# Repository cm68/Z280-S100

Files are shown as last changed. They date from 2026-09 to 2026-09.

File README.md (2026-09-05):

# Z280 S-100 CPU Card

A 16-bit **Zilog Z280** CPU card for the **IEEE-696 S-100** backplane. All the
glue logic lives in two **Atmel ATF1508AS** CPLDs, and the entire schematic +
PCB are Python-generated (`gen_kicad.py`, `gen_pcb.py`).

## Key characteristics

| | |
|---|---|
| CPU | Zilog Z280, 16-bit, Z-BUS @ **12 MHz** |
| Bus | IEEE-696 S-100, 100-pin edge connector |
| Glue logic | 2× Atmel ATF1508AS (128 macrocells each) |
| RAM | **2 MB** SRAM — 4× IS61C5128AS-25 (512K×8, 25 ns), word-addressed as 1M×16 |
| Boot ROM | **64 KB** EEPROM — 2× AT28C256 (32K×8) |
| Console | RS-232 via MAX232, 2×5 IDC header (J7) |
| Data-bus drive | 74F245 — meets the IEEE-696 24 mA sink spec |

The board is a **bus master** by default: it drives address, status, control and
data onto the backplane. The CPLDs split the work cleanly:

- **Control CPLD** (`U4`, `z280-s100-ctl.pld`) — "the decider". Arbitration, the
  master-bridge state machine, local-memory control, and the pre-qualified
  steering terms (`MST_RD/MST_WR/SLV_RD/SLV_WR`, `XFR16`, `SPLIT`, `SLAVE`).
- **Data CPLD** (`U5`, `z280-s100-ad.pld`) — "everything that moves bits". The
  AD0-15 byte mux to the S-100 DO/DI lanes, the burst address counter, and the
  byte lane.

Address decode is external: a 74F138 (SRAM window) + two 74F521 comparators
(flash window, slave window). The A3–A15 address lines are latched out through
two 74F573s, and the 16-bit data bus runs through two 74F245 transceivers.

## Memory map (24-bit address space)

| Range | Size | Decode | Device |
|---|---|---|---|
| `000000`–`1FFFFF` | 2 MB | 74F138 (`SRAM_WIN`) / 74F521 (`SLAVE_WIN`) | SRAM — board + temporary-master access |
| `F00000`–`F0FFFF` | 64 KB | 74F521, A23:A16 = `F0` | Boot EEPROM |

The boot EEPROM pair is word-addressed (flash A_n = byte A_{n+1}), so the two
parts span 64 KB. They are *not* socket-interchangeable with 27C256s (pin 27 is
`WE#` here, not A14).

## Local-memory DMA (temporary-master access)

Another S-100 master can take the bus and read/write this card's local SRAM
directly — DMA-style, without the Z280:

1. The temporary master (TMA) asserts **HOLD**; the control CPLD forwards the
   request to the Z280 (`Z_BUSREQ`) and waits for `Z_BUSACK`.
2. With `Z_BUSACK` low the board is a **slave**
   (`SLAVE = !Z_BUSACK # SLAVE_ONLY`): the address/status/control 74F245s
   reverse direction, the data 74F245s float (`S100_DODSB`), and the 74F573
   address latches float their outputs.
3. The TMA reaches this card's RAM through the **slave window** — a
   74F521 comparator (`SLAVE_WIN`, hardwired to `000000`–`1FFFFF`) that maps
   the TMA's address space onto the local SRAM.

The **SLAVE_ONLY** strap (J11) forces this state permanently, turning the card
into a plain memory-only card for bring-up and debug.

## Burst mode

The Z280's memory burst mode (consecutive accesses without re-presenting the
address) is handled in the data CPLD:

- a **2-bit burst address counter** (A1/A2) increments during a burst;
- the **byte lane** (A0) is derived from the low-address bit and the 16→8
  **SPLIT** flag, so byte and word cycles share one data path;
- **16-bit transfers** are detected from WORD and the S-100 **SIXTN**
  (16-bit-acknowledge) line: `SPLIT16 = WORD & !SIXTN`.

`SIXTN` is open-collector (wired-OR) and pulled up via R4, like the ready lines.

## Clock options

Two 24 MHz time-base footprints are laid out; populate exactly **one**:

- **Y1** — parallel-resonant crystal (HC49) across `XTALI`/`XTALO`, or
- **Y2** — a DIP-can oscillator (DIP-8 or DIP-14) driving `XTALI`.

The Z280 auto-detects the source: a crystal enables the on-chip oscillator, while
an external clock into `XTALI` bypasses it (leave `XTALO` open). There is no
strap for this. Either way the CPU clock is half the XTAL1 frequency, so
**24 MHz → 12 MHz processor clock**.

## Configuration jumpers

### J10 — BTI register straps (3×8 header)

The Z280 samples AD0-7 on the rising edge of reset to load its **Bus Timing &
Initialization (BTI)** register — the wait-state field, clock divider,
bootstrap and multiprocessor bits. J10 is a 3×8 header, one row per bit: the
centre pin selects +5V (logic 1) or GND (logic 0); a 74HCT244 (U21) drives the
value onto AD0-7 for the whole reset window.

**Default = `0b10001110`** (AD7…AD0): direct clock, no bootstrap, no
multiprocessor, **3 wait states**, bus clock = CPU clock.

### J11 — SLAVE_ONLY

2-pin header. **Open (default)** = normal bus master. **Jumper to +5V** =
permanent slave (memory-only card). R3 (1 kΩ) holds the line low when open.

### SLAVE_WIN — temporary-master window

A 74F521 comparator hardwired to `000000`–`1FFFFF` (the same 2 MB window as
SRAM) selects where a temporary master sees this card's SRAM. Not user-
configurable on this rev.

### FLASH_WE — boot-ROM write protection

The 28C256 `WE#` line is normally driven by the control CPLD (in-system EEPROM
programming). Strap it to +5V to hard-write-protect the boot ROM.

## Repository layout

| Path | Purpose |
|---|---|
| `gen_kicad.py` | Generates the schematic (`.kicad_sch`, `.kicad_sym`, `NOTES.md`) |
| `gen_pcb.py` | Generates the board (`.kicad_pcb`) — components, nets, power planes |
| `sync_pcb.py` | Reads hand-tweaked PCB placement back into `gen_pcb.py` |
| `z280-s100-ctl.pld` | Control CPLD (U4) logic — arbitration, FSM, memory control |
| `z280-s100-ad.pld` | Data CPLD (U5) logic — byte mux, burst counter, byte lane |
| `z280-s100-*.jed` | Compiled CPLD fuse maps (fit with WinCUPL + ProChip, flashed over JTAG) |

CPLDs are flashed over the JTAG header (TDI/TMS/TCK/TDO on pins 14/23/62/71).

## License

[CERN Open Hardware Licence Version 2 - Permissive](LICENSE) (CERN-OHL-P-2.0).
Fork, modify and build it freely — just don't claim you designed it: keep the
attribution.

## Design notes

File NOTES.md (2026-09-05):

# Design notes

Signal connectivity follows `extra/docs/z280-s100-cpu-card.md`. This board is
routed and fabricated; the notes below are the as-built reference.

## Pin numbers
- **Z280 (U1)**: 68-pin PLCC pinout verified — Z80 Family Data Book Fig. 2b
  (Z-BUS, OPT=1), transcribed from `extra/docs/z280-pins.tif`. Power = 2× VCC
  (18/19) + 4× GND (1/35/51/53); shared pins GREQ=CTIO0 (30), GACK=CTIN0 (32),
  EOP-A=INT-A (37), EOP-B=INT-B (36).
- **ATF1508 (U4/U5)**: pin numbers are now verified against the PLCC-84 pinout
  and match `z280-s100-ctl.pld` / `z280-s100-ad.pld` — JTAG TDI/TMS/TCK/TDO
  at 14/23/62/71 (dedicated), VCCINT 3/43 + VCCIO 13/26/38/53/66/78, GND
  7/19/32/42/47/59/72/82. The four DEDICATED INPUT pins are GCLR = 1 (global
  clear, active low), OE2 = 2, GCLK1 = 83, OE1 = 84 — GCLR/OE1/OE2 are tied to
  +5V (inactive) on both CPLDs; GCLK1 = 83 carries Z_CLK_IN. Regular signals
  must NOT sit on pins 1/2/84. Control sits at 59/64 I/O; the data CPLD was at
  62/64 until the A3–A15 latch moved back out to two 74F573s (freeing pins for
  the DO_DIR/DI_DIR buffer controls), so it now sits near 50/64. The control
  CPLD still declares Z_AS (pin 12) as a spare input — unused since LATCH_LE
  moved to the data CPLD; the fitter drops it and pin 12 stays high-Z.
- **Unused CPLD I/O (free pins for a board rev 2):** data CPLD U5 has **65, 67,
  68, 69, 70, 73, 74** free (7). Control CPLD U4 has **75, 76, 77** free (3),
  plus **pin 12 (Z_AS)** as a spare — declared but unused, so high-Z in the
  JEDEC; its trace is routed on this rev but can be re-purposed on the next.
- **AT28C256 flash (U10/U11)**: 28-pin DIP, JEDEC 28C256 layout (A14=1, A12=2,
  A7=3 … A0=10, DQ0=11 … DQ7=19, CE#=20, A10=21, OE#=22, A11=23, A9=24, A8=25,
  A13=26, WE#=27, VCC=28, VSS=14). Word-addressed (flash A_n = byte A_{n+1}),
  so A0–A14 = LA1–LA15 and the pair spans 64 KB. Pin 27 is WE# here — where a
  27C256 has A14 — so the two are NOT socket-interchangeable. No density
  jumpers; a 28C128/28C64 fits if pin 1 (A14) is strapped low.

## Corrected S-100 pinout
Taken from `extra/hardware/s100z80/s100_Z80 V2-cache.lib` (S100_MALE). Key pins:
sMEMR=47, sWO=97, sINP=46, sOUT=45, sM1=44, sINTA=96, sHLTA=48, sXTRQ=58,
SIXTN=60, pSYNC=76, pDBIN=78, pWR=77, pSTVAL=25, pHLDA=26, pRDY=72, XRDY=3,
HOLD=74, RESET=75, INT=73, NMI=12, ADSB=22, DODSB=23, SDSB=18, CDSB=19,
DO0=36/DO1=35/DO2=88/DO3=89/DO4=38/DO5=39/DO6=40/DO7=90,
DI0=95/DI1=94/DI2=41/DI3=42/DI4=91/DI5=92/DI6=93/DI7=43.

## Serial console (J7, 2×5 IDC)
- J7 pin 1 = RS-232 TX (from MAX232 T1OUT), pin 2 = RS-232 RX (to MAX232 R1IN),
  pins 3–10 = GND.  Cable pin 1 → DB9-3, pin 2 → DB9-2, any GND → DB9-5.
- MAX232 (U14) charge-pump (C1/C2) + V+/V-/VCC bypass (C3/C4/C5), 0.1 µF each,
  are placed on the schematic (C1–C5) and the board.

## Bus timing straps (J10 3x8 header + U21)
- One 3x8 header (24 pins) sets the value the Z280 samples on AD0-7 at reset to
  load its Bus Timing & Initialization register (low-8M wait states + clock
  divider). One row per bit: col 0 = +5V (HIGH), col 1 = signal (BTI_ADn),
  col 2 = GND (LOW). Shunt col1→+5V = 1, col1→GND = 0.
- The 74HCT244 (U21) tri-state driver presents that value on AD0-7 during the
  reset-config window: both /OE (pins 1, 19) tie to CFG_OE from the control
  CPLD. The CPLD asserts WAIT >=4 clocks before reset rises and holds it 15
  clocks after (datasheet p.541/545; 6 is the floor, the extra is free since the
  CPU sits on WAIT), and CFG_OE tracks that same dwell, so AD0-7 stays driven
  through the rising-edge sample and its hold time.
- Default strap = 0b10001110 (AD7..AD0; AD0 = BTI bit 0): direct clock on
  XTAL1, no bootstrap, no multiprocessor, 3 wait states, bus clock = CPU clock.
  AD7/AD3/AD2/AD1 = high (+5V), AD6/AD5/AD4/AD0 = low (GND). Every bit stays
  jumperable, so the wait field and clock divider can be changed in place.
- Reset must be held low >=512 XTAL1 clocks (~21 us at 24 MHz); the DS1813's
  ~100 ms power-on reset easily satisfies this.

## Clock source (crystal Y1 vs DIP oscillator Y2)
- Two time-base options are laid out, both 24 MHz: a parallel-resonant crystal
  Y1 (HC49) across XTALI/XTALO, and a DIP-can oscillator Y2 whose OUT drives
  XTALI. Populate ONE at build time -- they must not both be fitted (they both
  drive XTALI).
- The Z280 auto-detects the source (datasheet 9.2): a crystal across XTAL1/XTALO
  enables the on-chip oscillator, while an external clock into XTAL1 bypasses it
  (leave XTALO open). There is NO strap bit for this -- the J10 BTI straps set
  the clock scaling (CS), wait states, multiprocessor and bootstrap fields, not
  the clock source. In both modes the CPU clock is half the XTAL1 frequency, so
  either 24 MHz part gives a 12 MHz processor clock.
- Y2's footprint (z280-s100:Oscillator_DIP-8-14) takes either a full DIP-14 can
  (GND/OUT on 7/8, VCC on 14) or a half DIP-8 can (GND/OUT on 4/5, VCC on 8).
  Pads 4/7 and 5/8 are shorted by the netlist, and pad 1 (NC) floats.

## Data bus (74F245 transceivers, U25/U26)
- The S-100 DO0-7 / DI0-7 lanes are NOT driven by the CPLD any more. CPLD B's
  byte mux drives CPLD_DO0-7 / CPLD_DI0-7 into the A-side of two 74F245s whose
  B-side is the backplane. 74F245 (64 mA sink / 15 mA source) meets the
  IEEE-696 data-bus drive spec that the ATF1508 macrocell outputs cannot.
- DIR = DO_DIR / DI_DIR from the data CPLD (1 = drive the bus). /OE is tied low:
  a 245 in receive mode never drives the bus, so only DIR has to be right, and
  the DIRs are gated by S100_DODSB so a temporary master can float our drivers.

## Address latch (74F573, U2/U3)
- A3-A15 moved out of CPLD B into two 74F573s to free pins for DO_DIR/DI_DIR.
  LE = LATCH_LE (= ~AS: transparent while AS is low, holds on the rising edge);
  /OE = SLAVE so the latch floats its Q outputs when a TMA drives address inward.
  A0 (byte lane) and A1/A2 (burst counter) stay in the CPLD — they need the
  SPLIT / load-count logic a plain latch can't do.
- U2 latches AD3-AD10 -> A3-A10, U3 latches AD11-AD15 -> A11-A15 (D5-D7 tied
  low, Q5-Q7 unused). The S-100 address 245s now take A0-A15 directly (the old
  LA1-LA15 net names were a stale leftover from the in-CPLD latch).
- Labelled 74F573 / 74F245 (64 mA sink, ~5 ns) to meet the IEEE-696 24 mA
  bus-drive spec and keep the address path ahead of the 25 ns SRAM. 74ACT573 /
  74ACT245 are drop-in pin-compatible substitutes at build time if the F parts
  draw too much +5V (ACT still sinks the 24 mA the spec needs, at CMOS quiescent).

## Known issues
See [BUGS.md](BUGS.md).

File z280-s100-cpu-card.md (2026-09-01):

# Z280 S-100 CPU Card

> Reference design · rev 0

A 16-bit **Z-BUS → IEEE-696** bridge: word-wide SRAM with burst instruction fetch, exposed as an S-100 slave so temporary-master disk controllers can DMA straight into main memory.

| | |
|---|---|
| **CPU** | Zilog Z280 · Z-BUS mode (`OPT = 1`) |
| **Glue** | 2 × Microchip ATF1508 CPLD (control + data path) |
| **Bus** | S-100 / IEEE-696 · 16-bit, 8-bit fallback |
| **Memory** | 2 MB word-wide SRAM (4 sockets) + flash boot |

---

## 1. What the card is

The Z280 talks a multiplexed 16-bit **Z-BUS**; the S-100 bus talks an Intel-style split **DO/DI** bus with a status-latch / ready handshake. The two don't line up, so the card is mostly two CPLDs plus a row of latches and bus drivers. Its job splits cleanly in two:

- **Fast path** — the on-card SRAM hangs directly off the Z-BUS. Address is demultiplexed by the `AS` strobe into a pair of `74HC573` latches; the control CPLD only does chip-select (plus the burst address counter). Zero wait states, so the Z280's on-chip 256-byte cache fills in **burst** at bus speed.
- **Slow path** — anything outside local memory becomes an S-100 cycle. The CPLD decodes the Z-BUS status lines into the S-100 status byte, drives `pSYNC`/`pDBIN`/`pWR`, and holds the Z280's `WAIT` line until the addressed slave asserts `pRDY`.

The third requirement — **temporary-master access to local SRAM** — turns the card into a bus slave too. When a disk controller asserts `HOLD`, the card parks the CPU and re-exposes its SRAM to the backplane at a jumper-selected address window, so a DMA controller can read and write it directly.

```mermaid
flowchart LR
  subgraph CPU["Z280 — Z-BUS mode"]
    Z["Z280<br/>AD0-15 · A16-23<br/>AS DS R/W B/W ST IE OE"]
  end
  subgraph GLUE["bus glue — two CPLDs"]
    L["74HC573 ×2<br/>address latch"]
    A["ATF1508 A<br/>control: FSM · status · arb · mem"]
    D["ATF1508 B<br/>data: byte steering · slave handshake"]
  end
  subgraph LOCAL["local memory — fast path"]
    R["SRAM 16-bit<br/>4 × 512K×8, 2 banks"]
    F["Flash 16-bit<br/>boot ROM"]
  end
  B["S-100 backplane<br/>A · DO/DI · status · timing"]

  Z -- AD0-15 --> L
  Z -- AD0-15 --> D
  L -- LA0-15 --> R
  L -- LA0-15 --> F
  L -- LA0-15 --> A
  Z -- "A16-23 AS DS R/W B/W ST IE OE BUSACK" --> A
  A -- "/CS /OE /WE + burst A0-1" --> R
  A -- "/CS /OE /WE" --> F
  A -- "SLAVE · MASTER_ACTIVE · MASTER_WRITE · BYTE_SEL · XFR16" --> D
  D -- "AD0-15" --> R
  D -- "AD0-15" --> F
  D -- "DO / DI" --> B
  D -- "SRAM_WIN · FLASH_WIN · A20" --> A
  A -- "address · status · pSYNC/pDBIN/pWR · pHLDA" --> B
  Z -- "WAIT · BUSREQ" --> A
  B -- "HOLD · pRDY · INT · SIXTN" --> A
  B -- "sMEMR/sWO/sXTRQ · ADSB/DODSB/SDSB/CDSB" --> D
```

*Block diagram — the control CPLD (A) routes each Z-BUS transaction to either the fast local path or the slow S-100 path; the data-path CPLD (B) steers bytes between the shared AD bus and the S-100 DO/DI lanes.*

---

## 2. The bridge: Z-BUS → S-100

### Status decode

The Z-BUS identifies a transaction with four status lines (`ST3–0`) plus `R/W`. The CPLD translates that into the S-100 status byte on the falling edge of `pSYNC`:

| Z-BUS ST3–0 | Meaning | S-100 status | Strobe |
|---|---|---|---|
| `1000` | CPU mem, cacheable | `sMEMR` (+ `sWO` if write) | pDBIN / pWR |
| `1001` | CPU mem, non-cacheable | `sMEMR` (+ `sWO` if write) | pDBIN / pWR |
| `0010` | I/O transaction | `sINP` (read) / `sOUT` (write) | pDBIN / pWR |
| `0011` | Halt | `sHLTA` | — |
| `0100–0111` | INT ack A/B/C, NMI | `sINTA` | pDBIN (vector read) |
| `0001` | Refresh | — | ignored |
| `1010, 11xx, 1110–1111` | EPU / test-and-set | — | not used here |

`sWO` is simply the complement of `R/W` (R/W low = write). The cacheable vs non-cacheable split comes *from* the Z280's MMU page attributes — the card doesn't decide it; it just routes both as memory. Non-cacheable pages are how the OS keeps DMA buffers coherent (see §4).

### Master cycle

The whole bridge is the `WAIT`-stretched cycle below. The Z280 raises `AS` to start; the control CPLD holds `WAIT` low for the entire off-card cycle and releases it only when `pRDY` (or `XRDY`) says the slave is done.

```mermaid
sequenceDiagram
  autonumber
  participant Z as Z280
  participant C as CPLD
  participant B as S-100 slave
  Z->>C: AS↑ (addr + ST + R/W valid)
  C->>Z: WAIT↓ — hold CPU
  C->>C: decode ST→s*, latch A0-15
  C->>B: A0-23 + status
  C->>B: pSYNC↑ then ↓ (slaves latch status)
  alt read (R/W high)
    C->>B: pDBIN↑
    B-->>C: pRDY↑ — data valid on DI
    C->>Z: WAIT↑ (release)
    Z->>Z: sample DI at DS edge
  else write (R/W low)
    C->>B: DO = data, pWR↓
    B-->>C: pRDY↑
    C->>Z: WAIT↑ (release)
  end
  C->>B: drop pDBIN/pWR, status, address
```

*Master-mode memory cycle — the Z280 is stretched with WAIT while the control CPLD runs the S-100 handshake underneath it.*

### 16-bit handshake

When the Z280 does a word access (`B/W` low), the control CPLD asserts `sXTRQ` during `pSYNC`. If the addressed slave answers `SIXTN`, the transfer goes through the full 16-bit path — the two data buses ganged per IEEE-696, `DO0–7` carrying the even byte (A0=0) and `DI0–7` the odd byte (A0=1). If not, the control CPLD splits it into two 8-bit cycles on the low lane — two `pSYNC` groups, byte-address bit steering the low byte first. That's the entire "8-bit fallback": a single register in the control CPLD that remembers the master asked for 16 bits and the slave said no.

> **Timing to verify:** the exact edge where the Z-BUS samples `WAIT` relative to `DS`, and the `AS` setup/hold for latching `AD0–15`, come from the Z-BUS timing figures in the manual (ch. 13) — follow those, not the Z80-bus description in ch. 12.

---

## 3. Local memory & burst fetch

Local SRAM is **word-wide**: four 8-bit parts in two banks, data lines tied straight to the shared `AD0–15` bus, address from the demux latch — except the low two word-address bits, which come from the burst counter in the control CPLD. Reads use the Z280's own `IE` as the SRAM `/OE`, writes use `DS` gated with `R/W` as `/WE` — so a local access is *not* an S-100 cycle at all, just decode + chip-select. That's what makes burst work.

The Z280's cache fill is not a separate bus protocol — there's no `BURST` pin. It is **one Address Strobe followed by four Data Strobes** (§13-9): the CPU presents the address once on `AS`, then issues four back-to-back reads on `DS` without re-asserting the address. The card must therefore auto-increment the word address between strokes — a 2-bit counter in the control CPLD steps the SRAM's low two word-address bits (`A1`/`A2`, byte `A0` stays 0) on each `DS`. Because the SRAM answers in a single bus cycle with no wait states, the fill runs at full bus rate. This only works because those fetches stay on the fast path; the moment a fetch crosses to the backplane it picks up S-100 wait states.

> **Part choice:** the `IS61C5128AS-25` (512K×8, 25 ns, 5 V) is far inside the 12 MHz bus cycle (≈83 ns) — zero wait states and full burst with no decode-timing constraint at all. Four of them give 2 MB word-wide in two banks (each chip is one byte lane, `A0` selects the lane; `A20` selects the bank). Keep the traces to these fast parts short and decouple them well.

### Address map (physical, bus-decode view)

| Range | Size | Target | Notes |
|---|---|---|---|
| `000000–1FFFFF` | 2 MB | Local SRAM | Micronix runtime; zero-wait, burst, cacheable; two banks via A20 |
| `F00000–F0FFFF` | 64 KB | Boot EEPROM | 2× 28C256 (28-pin); CPLD overlays flash on the reset vector at power-up, then remaps |
| `200000–EFFFFF` | ~14 MB | S-100 memory | Off-card memory cards; mark non-cacheable |
| `I/O 0000–FDFF` | 64 KB | S-100 I/O | Ports FE/FF stay on-chip (UART, timers, MMU) |

The local/S-100 split is a decode in the data-path CPLD (B) of the `A16–23` address window, so it's re-programmable. The reset-vector overlay is a small latch in the control CPLD: flash answers at the reset address until boot code writes a remap bit.

---

## 4. Slave mode: DMA into local SRAM

This is the requirement that makes the card a real S-100 citizen. A disk controller that wants to DMA into Micronix's buffers takes over the bus as a **temporary master**; the CPU card must then look like ordinary memory. The MPZ80, HD/DMA and DJ/DMA all implement the full IEEE-696 handoff, so this card must too. Arbitration and access:

```mermaid
sequenceDiagram
  autonumber
  participant T as Disk controller (TMA)
  participant C as CPLD
  participant Z as Z280
  participant S as Local SRAM
  T->>C: HOLD↓ + DMA priority on DMA0-3
  C->>Z: BUSREQ↓
  Z-->>C: BUSACK↓ — CPU floats its own AD/A/ST/AS/DS
  C-->>T: pHLDA↑ (BUSACK inverted)
  T->>C: ADSB↓ DODSB↓ SDSB↓ — float addr / data-out / status drivers
  T->>C: CDSB↓ — float control drivers
  T->>C: A0-23 + sMEMR/sWO
  alt address inside slave window
    C->>S: /CS + /OE (or byte-laned /WE)
    S-->>C: data (A0-selected byte lane)
    C-->>T: DI data + pRDY↑
  else outside window
    C-->>T: no response (some other card answers)
  end
  T->>C: deassert CDSB/DODSB/ADSB/SDSB, then HOLD↑
  C->>Z: BUSREQ↑
  Z-->>C: BUSACK↑ — CPU resumes
```

*Temporary-master arbitration — the CPU answers HOLD with pHLDA, the TMA floats the card's drivers with the four disable lines, then the card serves its SRAM as a slave.*

- **Driver handoff (required).** The TMA does not rely on the CPU floating itself — it takes the drivers over by asserting the four IEEE-696 disable lines: `ADSB*` (address), `DODSB*` (data-out), `SDSB*` (status), `CDSB*` (control). These gate the data-path CPLD's buffer output-enables. `pHLDA` is **not** gated by `CDSB*` — it is the permanent master's exclusive output and stays driven. There is exactly one bus master; each temporary master gets the bus by going *through* the master (a temporary never yields directly to another temporary), so `pHLDA` has no contention to float against. The HD/DMA floats data/address/status before control (two-step); the DJ/DMA asserts `CDSB*` first — either way all four must be honored.
- **Slave window.** The SRAM appears on the backplane at a jumper/CPLD-selected base — default `000000–0FFFFF` so a 20-bit (or even 16-bit) DMA controller can reach every byte. The window must not collide with other cards on the backplane.
- **Byte lane.** The Morrow DMA controllers are 8-bit, so a slave access is a single byte. The word-wide SRAM is built from four 8-bit parts in two banks; `A0` selects the lane and `A20` the bank: `/OE`/`/WE` go to the chip holding the addressed byte, and data moves on `DO0–7`/`DI0–7`. `SIXTN` is asserted only in answer to `sXTRQ`, so a 16-bit TMA still gets a 16-bit cycle.
- **Ready.** As a slave the card drives `pRDY`/`XRDY` after the SRAM access time, exactly like any memory card.

> **Cache coherency is the trap.** A TMA write lands in SRAM while the Z280's 256-byte cache may hold a stale copy of that line. Two fixes: mark the DMA/shared buffers **non-cacheable** in the MMU (ST = `1001`, so the CPU always hits the bus), or have the OS flush/invalidate the cache after each DMA — cheap, since the whole cache is only 256 bytes. Pick one and make it a hard rule in the DMA driver.

The Z280's own four-channel on-chip DMA (with `DMASTB`/`EOP`) remains available for on-card peripherals that want flyby transfers without bus arbitration — but it isn't needed for the temporary-master requirement above.

---

## 5. Signal interfaces

### Z-BUS side (ch. 13, signals this card uses)

| Signal | Dir | Active | Role on this card |
|---|---|---|---|
| `AD0–15` | bidir | high | muxed addr/data → latch (addr) + SRAM/flash data + DO/DI path |
| `A16–23` | out | high | upper address → decode + S-100 A16–23 |
| `AS` | out | low | address strobe — rising edge latches AD0-15, starts FSM |
| `DS` | out | low | data strobe — times data, reference for WAIT sample |
| `R/W` | out | low=wr | direction → sWO, SRAM /WE |
| `B/W` | out | low=word | word vs byte → sXTRQ / split |
| `ST3–0` | out | high | status → decoded to S-100 s* lines |
| `IE / OE` | out | low | read / write enables — gate DI into AD, AD onto DO/SRAM |
| `WAIT` | in | low | held low while an S-100 cycle completes |
| `BUSREQ / BUSACK` | in / out | low | bus handoff for temporary-master arbitration |
| `INT / NMI` | in | low | interrupts from backplane / local |
| `RESET` | in | low | power-on + S-100 pRESET |
| `XTALI/XTALO · CLK` | in/out | — | crystal in, bus clock out (FSM timing ref) |
| `OPT` | in | — | tie high = Z-BUS mode |
| `TxD / RxD` | out / in | high | console UART |

### S-100 side (signals this card drives or reads)

| Signal | Master | Slave | Purpose |
|---|---|---|---|
| `A0–23` | drive | receive | address |
| `DO0–7` | drive (write) | receive (write) | data out — the even byte (A0=0) |
| `DI0–7` | receive (read) | drive (read) | data in — the odd byte (A0=1) |
| `sMEMR/sWO/sINP/sOUT/sINTA/sHLTA` | drive | receive | status |
| `sXTRQ` | drive | receive | 16-bit request |
| `SIXTN` | receive | drive | 16-bit acknowledge |
| `pSYNC/pSTVAL/pDBIN/pWR` | drive | receive | cycle timing |
| `pHLDA` | drive | — | grant bus to a TMA (active high, from BUSACK) |
| `HOLD` | receive | — | temporary-master request |
| `ADSB` | receive | — | TMA disables my address drivers |
| `DODSB` | receive | — | TMA disables my data-out drivers |
| `SDSB` | receive | — | TMA disables my status drivers |
| `CDSB` | receive | — | TMA disables my control drivers |
| `pRDY / XRDY` | receive | drive | ready handshake |
| `INT / NMI / pRESET` | receive | receive | interrupts, reset |

> **Pin numbers** are per IEEE-696 and your backplane — the ones this card leans on are `pSYNC`=76, `pWR`=77, `pDBIN`=78, `sXTRQ`=58, `SIXTN`=60, `HOLD`=74, `pHLDA`=26 (active high), the disable lines `SDSB`=18, `CDSB`=19, `ADSB`=22, `DODSB`=23, power at 1 (+8V), 2 (+16V), 51 (+8V), 52 (−16V), 50/100 (GND). Confirm the address/data pins against the standard before wiring.

---

## 6. CPLDs: two ATF1508

Two **ATF1508** parts (128 macrocells, 5 V, JTAG/ISP, 84-pin PLCC, 64 I/O each) split the design down a clean seam: everything that *decides* a cycle lives in the **control CPLD (A)**, everything that *moves bytes* lives in the **data-path CPLD (B)**. The original single-part design used ~70 macrocells but 69 general I/O — past the 64-I/O ceiling — so two parts give 128 I/O and 256 macrocells of headroom. Bonus: each CPLD re-spins independently over JTAG, so a master-FSM fix doesn't touch the byte steering and vice versa.

### Control CPLD (A) — the decider

Owns the Z-BUS interface and never touches a data line:

- **Master FSM** — idles until `AS`, decides local vs S-100, runs the WAIT-stretched S-100 handshake, and holds the 16→8 split latch.
- **Status/control generation** — decodes `ST3–0` into the S-100 status byte and the `pSYNC`/`pDBIN`/`pWR` timing.
- **Local memory control** — SRAM/flash chip-selects, byte-laned `/WE`, and the **burst counter** (the 2-bit loadable counter that auto-increments the SRAM word address on each `DS`).
- **Arbitration** — `HOLD`→`BUSREQ`→`pHLDA` and the `SLAVE`/`MASTER` split.
- **Interrupts** — `INT`/`NMI` routing.

It only *reads* `pRDY`/`XRDY`/`SIXTN`; the open-drain drive of those lives in B.

### Data-path CPLD (B) — the mover

Hangs `AD0–15` (16 bidir) on the shared AD bus and does the IEEE-696 even/odd byte steering *inside*, driving `DO0–7`/`DI0–7` out through two **74F245** transceivers — the ATF1508 macrocell outputs can't meet the IEEE-696 24 mA data-bus sink spec on their own:

- **Byte mux (2×2 crossbar)** — `DO0–7` carries the even byte (A0=0), `DI0–7` the odd (A0=1); the mux steers each byte to the right `AD` lane and reverses for 8-bit split cycles.
- **Data-bus buffers** — `DO_DIR`/`DI_DIR` outputs drive the two 74F245 `DIR` pins (`/OE` tied low); both are `DODSB`-gated so a temporary master can float the data drivers.
- **Address latch** — the plain `A3–A15` half of the demux latch lives in two 74HC573s (`LATCH_LE = ~AS`, `/OE = SLAVE`), freeing pins for `DO_DIR`/`DI_DIR`; `A0` (byte lane) and `A1`/`A2` (burst counter) stay here.
- **Slave handshake** — open-drain `SIXTN`/`pRDY`/`XRDY` drive.
- **Buffer OE/DIR** — the address/status/control 74HCT245 drivers, gated by `ADSB`/`SDSB`/`CDSB`.

### Handoff between the two

Five steering decisions A computes that B can't see, three decode lines B computes that A needs:

```
A ──► B:  SLAVE · MASTER_ACTIVE · MASTER_WRITE · BYTE_SEL · XFR16
B ──► A:  SRAM_WIN · FLASH_WIN · A20
```

### Pin budgets

| CPLD | Inputs | Bidir | Outputs | Total signals |
|---|---|---|---|---|
| A — control | 25 | 8 | 28 | 61 |
| B — data path | 11 | 33 | 6 | 50 |

Both fit the 60 general I/O + GCK1 on the 84-pin PLCC (the four JTAG pins are dedicated). The 7 ns grade is fine — two parts cost nothing new when they're already on hand. Moving the `A3–A15` latch out to the 74HC573s dropped the data CPLD from ~100% I/O to 53/64 (82%).

### JTAG programming

One 1×6 header programs both parts in a single chain: `TCK`/`TMS` wired in parallel, `TDI`→A→B→`TDO` in series. The ISP tool selects a device positionally — chain order, not an address — by loading the target's ISP instruction and BYPASS into the others, then shifting data to just that part (see §9).

---

## 7. I/O, clock, power

**Console.** The Z280's on-chip UART is the console. `TxD`/`RxD` go through a `MAX232` (or 1488/1489) to a DE-9 — no SIO card needed. Baud from the on-chip generator if available, else a 1.8432 MHz oscillator for standard rates.

**Interrupts.** Backplane `INT` → Z280 `INT` (level), `NMI` → `NMI`. Vectored interrupts work via the `sINTA` cycle (ST = `0100–0111`), where the Z280 reads the vector off the bus like any I/O read — wire it if a controller needs it; otherwise keep interrupts flat.

**Clock.** A crystal on `XTALI`/`XTALO`; the processor clock is always **half the crystal frequency**, and the bus clock (output on `CLK`) is the processor clock divided by 1, 2, or 4 via the `CS` field of the Bus Timing & Initialization register (`00`=÷2 default, `01`=÷1, `10`=÷4, `11`=reserved). The `Z8028012` is rated for a **12 MHz processor clock**, so it needs a **24 MHz crystal** — the datasheet's "10 MHz"/"12.5 MHz" columns are processor clocks (XTALI = 20/25 MHz), confirming the part-number MHz is the CPU clock, not the crystal. For full-bore SRAM, set `CS`=`01` (÷1): the bus clock equals the CPU clock, **12 MHz**, so local SRAM runs zero-wait/burst at full speed while the CPLD WAIT-stretches off-card S-100 cycles to ≤6 MHz. `CS` is only writable at reset (WAIT asserted → `AD0–7` load); the ÷2 default gives a 6 MHz bus without that step. The BTI register value is set at reset by eight 3-pin jumpers (`J10–J17`) feeding a 74HCT244 (`U21`) whose tri-state outputs drive `AD0–7`; the control CPLD asserts WAIT ≥4 clocks before reset rises and holds it 15 clocks after (datasheet p.541/545; 6 is the floor, the rest is free), and `CFG_OE` tracks that same dwell to keep `AD0–7` driven through the sample. Default strap = `0b10001110` (AD7..AD0; AD4=0): direct clock, no bootstrap, no multiprocessor, 3 wait states, bus clock = CPU clock — the wait field and clock divider stay jumperable.

**Reset.** A reset supervisor (`DS1813`) holds `RESET` low ~100 ms at power-on, OR'd with backplane `pRESET`. The Z280 needs ≥512 XTAL1 clocks (~21 µs at 24 MHz) of reset, so the 100 ms is ample. The same net resets both CPLDs and re-asserts the flash-over-reset-vector latch.

**Power.** Regulate the +8 V rail down to +5 V with a `7805` (heatsink) or a small switcher. Budget ≈ 0.6 A: Z280 ~200 mA, two ATF1508s ~100 mA, four SRAMs, flash, drivers, MAX232. 4-layer board (power + ground planes), 0.1 µF per power pin plus bulk 10–47 µF.

---

## 8. Bill of materials

| Ref | Part | Notes |
|---|---|---|
| U1 | Zilog Z280MPU | 68-pin PLCC (or PGA); OPT tied high |
| U4 | Microchip ATF1508AS | 84-pin PLCC, 7 ns — control CPLD (A) |
| U5 | Microchip ATF1508AS | 84-pin PLCC, 7 ns — data-path CPLD (B) |
| U2–U3 | 74HC573 ×2 | address demux latch A3–A15 (`LATCH_LE = ~AS`, `/OE = SLAVE`; A0/A1/A2 stay in CPLD B) |
| U6–U9 | IS61C5128AS-25 ×4 | 512K×8, 25 ns SRAM = 2 MB word-wide, two banks (on DIP carriers) |
| U10–U11 | AT28C256 ×2 | 32K×8 EEPROM = 64 KB boot (28-pin DIP, JEDEC; no density jumpers) |
| U15–U17 | 74HCT245 ×3 | S-100 address drivers (A0–23) |
| U18 | 74HCT245 | S-100 status driver |
| U19 | 74HCT245 | S-100 control driver |
| U20 | 74HCT245 | pHLDA driver — one signal, full part (DIP-only constraint) |
| U25–U26 | 74F245 ×2 | S-100 data-bus transceivers (DO0-7, DI0-7) — 64 mA sink / 15 mA source meets IEEE-696 |
| U14 | MAX232 (or 1488/1489) | console level shifter |
| U13 | DS1813 | reset supervisor |
| U12 | PSU5a switcher | +5 V from +8 V rail, 3 A, no heatsink |
| Y1 | 24 MHz crystal | Z280 time base (CPU clock = crystal ÷ 2) |
| J2 | 1×6 pin header | JTAG programming chain (TDI→A→B→TDO) |
| J10–J17 | 3-pin jumper ×8 | BTI reset straps — set the AD0-7 reset value (wait states + clock divider) |
| U21 | 74HCT244 | tri-state BTI driver — presents the strap value on AD0-7 during reset, high-Z after |
| — | S-100 edge connector | 100-pin, gold fingers |

> Byte steering lives inside CPLD B, but the S-100 data lanes are now driven through two 74F245 transceivers (U25/U26) — the ATF1508 outputs can't meet the IEEE-696 data-bus drive spec. The address/status/control/pHLDA drivers (U15–U20) are 74HCT245; exact counts follow from the pin budget at PCB time.

---

## 9. Bring-up order

Build and test in this sequence — each step only exercises the previous one:

1. **Program the CPLDs** — chain both ATF1508s on the JTAG header and load `control.jed` (A, nearest TDI) and `data.jed` (B, nearest TDO). Verify each device enumerates in the chain.
2. **CPU alive** — Z280 + clock + reset only. Confirm `CLK`, that `RESET` is not stuck, and the CPU drives `AS`.
3. **Boot + RAM** — flash over the reset vector, SRAM decode. Run a monitor from flash; write/read/verify all 2 MB of SRAM (both banks) at full bus speed, then exercise a burst fill and check the word-address counter steps.
4. **Console** — get the on-chip UART speaking at the target baud before anything else.
5. **Master mode** — plug in a known-good S-100 memory card, read/write it through the bridge, confirm wait states hold the CPU correctly.
6. **16-bit** — exercise word accesses against a 16-bit-capable slave, then against an 8-bit-only card to prove the split.
7. **Slave mode** — from a second master (or a bus test jig), assert `HOLD`, DMA into the slave window, verify the CPU sees the bytes and the cache is coherent.

---

## 10. Open items to pin down

- **Reset vector location** — confirm where the Z280 fetches after reset (ch. 11) so the flash overlay sits at the right address.
- **Z-BUS timing figures** — exact `AS`/`DS`/`WAIT` edge relationships (ch. 13), for the WAIT-release register timing.
- **12 MHz bin spec** — resolved from `Z280-datasheet.pdf`: the 10/12.5 MHz columns are processor clocks (XTALI = 20/25 MHz), so `Z8028012` = 12 MHz CPU clock → 24 MHz crystal. Confirm the exact bin (12.0 vs 12.5 MHz) before ordering the crystal.
- **Cache control** — the exact way to mark a region non-cacheable, and/or the flush/invalidate sequence for the DMA driver.
- **Slave-window base** — agree the DMA address convention with whatever disk controller ships in this system.
- **Backplane pin map** — verify the IEEE-696 address/data pin numbers before netlisting.
- **ATF1508 pin map** — the `.pld` pin numbers are placeholders; verify against the 84-pin PLCC pinout (including the four dedicated JTAG pins) before netlisting.

---

## Sources

- [Konamiman/Z280TechnicalManual](https://github.com/Konamiman/Z280TechnicalManual) — transcript of the Zilog Z280 Technical Manual; Z-BUS pin functions and ST0–ST3 encodings (ch. 13), bus interface timing (ch. 12).
- [Zilog Z80 Family Data Book (1989)](https://archive.org/stream/Zilog-Z80familyDataBook1989OCR/Zilog-Z80familyDataBook1989OCR_djvu.txt) — Z280 pin configurations and Z-BUS functional blocks.
- [S-100 bus reference (retrocmp.de)](https://retrocmp.de/northstar-hrz/ns-hrz_p07_s100.htm) and the [S-100 Bus Handbook](https://archive.org/stream/Bus-TheS-100BusHandbook-DaveBurskyOCR/Bus-TheS-100BusHandbook-DaveBurskyOCR_djvu.txt) — IEEE-696 status, timing, and DMA signal definitions.

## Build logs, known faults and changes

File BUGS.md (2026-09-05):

# Known bugs

## S-100 bus RESET does not reset the board

The DS1813 (U13) power-on reset drives `Z_RESET` directly, but the S-100 bus
`RESET` line is not OR'd into it. As a result, an S-100 bus RESET (another bus
master, or a front-panel reset) will not reset the Z280 or the CPLDs — the card
only resets on power-on.

**Fix (board rev 2):** OR `S100_RESET` into `Z_RESET` before it reaches the
CPLD and the Z280 — a diode-OR of the DS1813 reset and `S100_RESET`, or route
`S100_RESET` into the control CPLD and OR it in logic.

## Future improvements

- **Configurable slave window** — `SLAVE_WIN` (U24 74F521) is hardwired to
  `000000`–`1FFFFF`, the same 2 MB window as `SRAM_WIN`. Strapping the
  high-order address lines (A16–A23) with jumpers or a DIP switch would let a
  temporary master see the local SRAM at a movable 2 MB window, avoiding
  address conflicts with other cards on the bus.

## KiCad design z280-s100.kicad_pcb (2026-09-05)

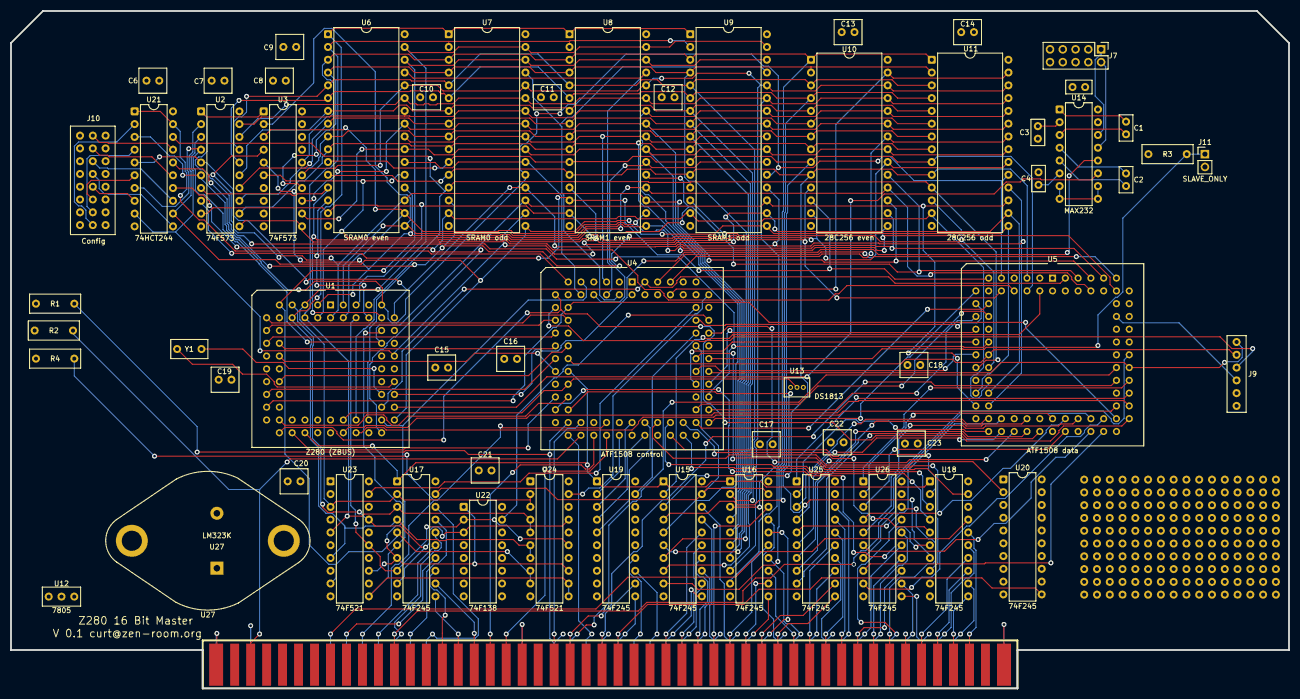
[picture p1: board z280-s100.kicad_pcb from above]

Board: 4 copper layers, 254.0 x 134.6 mm, 60 parts (0 on the bottom side), 202 nets.

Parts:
C1, C2, C3, C4, C5: 0.1uF; C_Disc_D5.0mm_W2.5mm_P2.50mm
C6, C7, C8, C9, C10, C11, C12, C13, C14, C15, C16, C17, C18, C19, C20, C21, C22, C23: 0.1uF; CAP-2
J7: Serial (2x5); PinHeader_2x05_P2.54mm_Vertical
J9: JTAG; HDR-6
J10: Config; HDR-3x8
J11: SLAVE_ONLY; PinHeader_1x02_P2.54mm_Vertical
R1: 1k pRDY; HDR-2
R2: 1k XRDY; HDR-2
R3: 1k SLAVE_ONLY; HDR-2
R4: 1k SIXTN; HDR-2
U1: Z280 (ZBUS); PLCC-68_THT-Socket
U2, U3: 74F573; DIP-20_W7.62mm
U4: ATF1508 control; PLCC-84_THT-Socket
U5: ATF1508 data; PLCC-84_THT-Socket
U6: SRAM0 even; DIP-32_W15.24mm
U7: SRAM0 odd; DIP-32_W15.24mm
U8: SRAM1 even; DIP-32_W15.24mm
U9: SRAM1 odd; DIP-32_W15.24mm
U10: 28C256 even; DIP-28_W15.24mm
U11: 28C256 odd; DIP-28_W15.24mm
U12: 7805; HDR-3
U13: DS1813; HDR-3
U14: MAX232; DIP-16_W7.62mm
U15, U16, U17, U18, U19, U20, U25, U26: 74F245; DIP-20_W7.62mm
U21: 74HCT244; DIP-20_W7.62mm
U22: 74F138; DIP-16_W7.62mm
U23, U24: 74F521; DIP-20_W7.62mm
U27: LM323K; TO-3
V 0.1 curt@zen-room.org: Z280 16 Bit Master; S100_MALE
Y1: 24 MHz crystal; HDR-2

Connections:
+5V: C5.1, C6.1, C7.1, C8.1, C9.1, C10.1, C11.1, C12.1, C13.1, C14.1, C15.1, C16.1, C17.1, C18.1, C19.1, C20.1, C21.1, C22.1, C23.1, J9.6, J10.1, J10.4, J10.7, J10.10, J10.13, J10.16, J10.19, J10.22, J11.2, R1.1, R2.1, R4.1, U1.18, U1.19, U1.34, U2.20, U3.20, U4.1, U4.2, U4.3, U4.13, U4.26, U4.38, U4.43, U4.53, U4.66, U4.78, U4.84, U5.1, U5.2, U5.3, U5.13, U5.26, U5.38, U5.43, U5.53, U5.66, U5.78, U5.84, U6.32, U7.32, U8.32, U9.32, U10.28, U11.28, U12.3, U13.3, U14.16, U15.20, U16.20, U17.20, U18.20, U19.20, U20.1, U20.20, U21.20, U22.6, U22.16, U23.12, U23.14, U23.16, U23.18, U23.20, U24.20, U25.20, U26.20, U27.2
+8V: U12.1, U27.1, V 0.1 curt@zen-room.org.1, V 0.1 curt@zen-room.org.51
A0: U5.4, U15.2
A1: U5.5, U6.12, U7.12, U8.12, U9.12, U10.10, U11.10, U15.3
A2: U5.6, U6.11, U7.11, U8.11, U9.11, U10.9, U11.9, U15.4
A3: U2.12, U6.10, U7.10, U8.10, U9.10, U10.8, U11.8, U15.5
A4: U2.13, U6.9, U7.9, U8.9, U9.9, U10.7, U11.7, U15.6
A5: U2.14, U6.8, U7.8, U8.8, U9.8, U10.6, U11.6, U15.7
A6: U2.15, U6.7, U7.7, U8.7, U9.7, U10.5, U11.5, U15.8
A7: U2.16, U6.6, U7.6, U8.6, U9.6, U10.4, U11.4, U15.9
A8: U2.17, U6.5, U7.5, U8.5, U9.5, U10.3, U11.3, U16.2
A9: U2.18, U6.27, U7.27, U8.27, U9.27, U10.25, U11.25, U16.3
A10: U2.19, U6.26, U7.26, U8.26, U9.26, U10.24, U11.24, U16.4
A11: U3.12, U6.23, U7.23, U8.23, U9.23, U10.21, U11.21, U16.5
A12: U3.13, U6.25, U7.25, U8.25, U9.25, U10.23, U11.23, U16.6
A13: U3.14, U6.4, U7.4, U8.4, U9.4, U10.2, U11.2, U16.7
A14: U3.15, U6.28, U7.28, U8.28, U9.28, U10.26, U11.26, U16.8
A15: U3.16, U6.3, U7.3, U8.3, U9.3, U10.1, U11.1, U16.9
A16: U1.5, U6.31, U7.31, U8.31, U9.31, U17.2, U23.3, U24.2, U24.3
A17: U1.6, U6.2, U7.2, U8.2, U9.2, U17.3, U23.5, U24.4, U24.5
A18: U1.8, U6.1, U7.1, U8.1, U9.1, U17.4, U23.7, U24.6, U24.7
A19: U1.9, U6.30, U7.30, U8.30, U9.30, U17.5, U23.9, U24.8, U24.9
A20: U1.45, U4.9, U17.6, U23.11, U24.11, U24.12
A21: U1.59, U17.7, U22.1, U23.13, U24.13
A22: U1.66, U17.8, U22.2, U23.15, U24.15
A23: U1.7, U17.9, U22.3, U23.17, U24.17
AD0: U1.40, U5.24, U7.13, U9.13, U11.11, U21.18
AD1: U1.42, U5.25, U7.14, U9.14, U11.12, U21.16
AD2: U1.43, U5.27, U7.15, U9.15, U11.13, U21.14
AD3: U1.44, U2.2, U5.28, U7.17, U9.17, U11.15, U21.12
AD4: U1.54, U2.3, U5.29, U7.18, U9.18, U11.16, U21.9
AD5: U1.57, U2.4, U5.30, U7.19, U9.19, U11.17, U21.7
AD6: U1.60, U2.5, U5.31, U7.20, U9.20, U11.18, U21.5
AD7: U1.61, U2.6, U5.9, U7.21, U9.21, U11.19, U21.3
AD8: U1.62, U2.7, U5.10, U6.13, U8.13, U10.11
AD9: U1.64, U2.8, U5.11, U6.14, U8.14, U10.12
AD10: U1.65, U2.9, U5.75, U6.15, U8.15, U10.13
AD11: U1.67, U3.2, U5.76, U6.17, U8.17, U10.15
AD12: U1.68, U3.3, U5.77, U6.18, U8.18, U10.16
AD13: U1.2, U3.4, U5.79, U6.19, U8.19, U10.17
AD14: U1.3, U3.5, U5.80, U6.20, U8.20, U10.18
AD15: U1.4, U3.6, U5.81, U6.21, U8.21, U10.19
BTI_AD0: J10.2, U21.2
BTI_AD1: J10.5, U21.4
BTI_AD2: J10.8, U21.6
BTI_AD3: J10.11, U21.8
BTI_AD4: J10.14, U21.11
BTI_AD5: J10.17, U21.13
BTI_AD6: J10.20, U21.15
BTI_AD7: J10.23, U21.17
CFG_OE: U4.11, U21.1, U21.19
CPLD_DI0: U5.44, U26.2
CPLD_DI1: U5.45, U26.3
CPLD_DI2: U5.46, U26.4
CPLD_DI3: U5.48, U26.5
CPLD_DI4: U5.49, U26.6
CPLD_DI5: U5.50, U26.7
CPLD_DI6: U5.51, U26.8
CPLD_DI7: U5.52, U26.9
CPLD_DO0: U5.33, U25.2
CPLD_DO1: U5.34, U25.3
CPLD_DO2: U5.35, U25.4
CPLD_DO3: U5.36, U25.5
CPLD_DO4: U5.37, U25.6
CPLD_DO5: U5.39, U25.7
CPLD_DO6: U5.40, U25.8
CPLD_DO7: U5.41, U25.9
CPLD_pDBIN: U4.45, U19.4
CPLD_pHLDA: U4.48, U20.2
CPLD_pSTVAL: U4.44, U19.3
CPLD_pSYNC: U4.41, U19.2
CPLD_pWR: U4.46, U19.5
CPLD_sHLTA: U4.31, U18.7
CPLD_sINP: U4.51, U18.4
CPLD_sINTA: U4.30, U18.6
CPLD_sMEMR: U4.49, U18.2
CPLD_sOUT: U4.52, U18.5
CPLD_sWO: U4.50, U18.3
CPLD_sXTRQ: U4.65, U18.8
DI_DIR: U5.60, U26.1
DO_DIR: U5.58, U25.1
FLASH_CE: U4.81, U10.20, U11.20
FLASH_OE: U4.79, U10.22, U11.22
FLASH_WE: U4.80, U10.27, U11.27
FLASH_WIN: U4.73, U23.19
GND: C3.2, C4.2, C5.2, C6.2, C7.2, C8.2, C9.2, C10.2, C11.2, C12.2, C13.2, C14.2, C15.2, C16.2, C17.2, C18.2, C19.2, C20.2, C21.2, C22.2, C23.2, J7.3, J7.4, J7.5, J7.6, J7.7, J7.8, J7.9, J7.10, J9.5, J10.3, J10.6, J10.9, J10.12, J10.15, J10.18, J10.21, J10.24, R3.1, U1.1, U1.35, U1.51, U1.53, U2.10, U3.7, U3.8, U3.9, U3.10, U4.7, U4.19, U4.32, U4.42, U4.47, U4.59, U4.72, U4.82, U5.7, U5.19, U5.32, U5.42, U5.47, U5.59, U5.72, U5.82, U6.16, U7.16, U8.16, U9.16, U10.14, U11.14, U12.2, U13.1, U14.15, U15.10, U16.10, U17.10, U18.10, U19.10, U20.3, U20.4, U20.5, U20.6, U20.7, U20.8, U20.9, U20.10, U20.19, U21.10, U22.4, U22.5, U22.8, U23.1, U23.2, U23.4, U23.6, U23.8, U23.10, U24.1, U24.10, U24.14, U24.16, U24.18, U25.10, U25.19, U26.10, U26.19, U27.3, V 0.1 curt@zen-room.org.20, V 0.1 curt@zen-room.org.50, V 0.1 curt@zen-room.org.53, V 0.1 curt@zen-room.org.70, V 0.1 curt@zen-room.org.100
JTAG_CHAIN: U4.71, U5.14
JTAG_TCK: J9.1, U4.62, U5.62
JTAG_TDI: J9.3, U4.14
JTAG_TDO: J9.4, U5.71
JTAG_TMS: J9.2, U4.23, U5.23
LA0: U4.63, U5.22
LATCH_LE: U2.11, U3.11, U5.8
MAX_C1M: C1.2, U14.3
MAX_C1P: C1.1, U14.1
MAX_C2M: C2.2, U14.5
MAX_C2P: C2.1, U14.4
MAX_RS232_RX: J7.2, U14.13
MAX_RS232_TX: J7.1, U14.14
MAX_VM: C4.1, U14.6
MAX_VP: C3.1, U14.2
MEM_CE0: U4.10, U6.22, U7.22
MEM_CE1: U4.8, U8.22, U9.22
MEM_OE: U4.5, U6.24, U7.24, U8.24, U9.24
MEM_WE_H: U4.4, U7.29, U9.29
MEM_WE_L: U4.6, U6.29, U8.29
MST_RD: U4.54, U5.12
MST_WR: U4.55, U5.15
NC: U14.7, U14.8, U14.9, U14.10
S100_A0: U15.11, V 0.1 curt@zen-room.org.79
S100_A1: U15.12, V 0.1 curt@zen-room.org.80
S100_A2: U15.13, V 0.1 curt@zen-room.org.81
S100_A3: U15.14, V 0.1 curt@zen-room.org.31
S100_A4: U15.15, V 0.1 curt@zen-room.org.30
S100_A5: U15.16, V 0.1 curt@zen-room.org.29
S100_A6: U15.17, V 0.1 curt@zen-room.org.82
S100_A7: U15.18, V 0.1 curt@zen-room.org.83
S100_A8: U16.11, V 0.1 curt@zen-room.org.84
S100_A9: U16.12, V 0.1 curt@zen-room.org.34
S100_A10: U16.13, V 0.1 curt@zen-room.org.37
S100_A11: U16.14, V 0.1 curt@zen-room.org.87
S100_A12: U16.15, V 0.1 curt@zen-room.org.33
S100_A13: U16.16, V 0.1 curt@zen-room.org.85
S100_A14: U16.17, V 0.1 curt@zen-room.org.86
S100_A15: U16.18, V 0.1 curt@zen-room.org.32
S100_A16: U17.11, V 0.1 curt@zen-room.org.16
S100_A17: U17.12, V 0.1 curt@zen-room.org.17
S100_A18: U17.13, V 0.1 curt@zen-room.org.15
S100_A19: U17.14, V 0.1 curt@zen-room.org.59
S100_A20: U17.15, V 0.1 curt@zen-room.org.61
S100_A21: U17.16, V 0.1 curt@zen-room.org.62
S100_A22: U17.17, V 0.1 curt@zen-room.org.63
S100_A23: U17.18, V 0.1 curt@zen-room.org.64
S100_ADSB: U4.36, V 0.1 curt@zen-room.org.22
S100_A_OE: U4.67, U15.19, U16.19, U17.19
S100_CDSB: U4.39, V 0.1 curt@zen-room.org.19
S100_C_OE: U4.69, U19.19
S100_DI0: U26.11, V 0.1 curt@zen-room.org.95
S100_DI1: U26.12, V 0.1 curt@zen-room.org.94
S100_DI2: U26.13, V 0.1 curt@zen-room.org.41
S100_DI3: U26.14, V 0.1 curt@zen-room.org.42
S100_DI4: U26.15, V 0.1 curt@zen-room.org.91
S100_DI5: U26.16, V 0.1 curt@zen-room.org.92
S100_DI6: U26.17, V 0.1 curt@zen-room.org.93
S100_DI7: U26.18, V 0.1 curt@zen-room.org.43
S100_DO0: U25.11, V 0.1 curt@zen-room.org.36
S100_DO1: U25.12, V 0.1 curt@zen-room.org.35
S100_DO2: U25.13, V 0.1 curt@zen-room.org.88
S100_DO3: U25.14, V 0.1 curt@zen-room.org.89
S100_DO4: U25.15, V 0.1 curt@zen-room.org.38
S100_DO5: U25.16, V 0.1 curt@zen-room.org.39
S100_DO6: U25.17, V 0.1 curt@zen-room.org.40
S100_DO7: U25.18, V 0.1 curt@zen-room.org.90
S100_DODSB: U5.61, V 0.1 curt@zen-room.org.23
S100_HOLD: U4.33, V 0.1 curt@zen-room.org.74
S100_INT: U5.63, V 0.1 curt@zen-room.org.73
S100_NMI: U5.64, V 0.1 curt@zen-room.org.12
S100_SDSB: U4.37, V 0.1 curt@zen-room.org.18
S100_SIXTN: R4.2, U4.40, V 0.1 curt@zen-room.org.60
S100_S_OE: U4.68, U18.19
S100_XRDY: R2.2, U4.35, V 0.1 curt@zen-room.org.3
S100_pDBIN: U19.13, V 0.1 curt@zen-room.org.78
S100_pHLDA: U20.11, V 0.1 curt@zen-room.org.26
S100_pRDY: R1.2, U4.34, V 0.1 curt@zen-room.org.72
S100_pSTVAL: U19.12, V 0.1 curt@zen-room.org.25
S100_pSYNC: U19.11, V 0.1 curt@zen-room.org.76
S100_pWR: U19.14, V 0.1 curt@zen-room.org.77
S100_sHLTA: U18.16, V 0.1 curt@zen-room.org.48
S100_sINP: U18.13, V 0.1 curt@zen-room.org.46
S100_sINTA: U18.15, V 0.1 curt@zen-room.org.96
S100_sMEMR: U18.11, V 0.1 curt@zen-room.org.47
S100_sOUT: U18.14, V 0.1 curt@zen-room.org.45
S100_sWO: U18.12, V 0.1 curt@zen-room.org.97
S100_sXTRQ: U18.17, V 0.1 curt@zen-room.org.58
SLAVE: U2.1, U3.1, U4.58, U5.21
SLAVE_ONLY: J11.1, R3.2, U4.64
SLAVE_WIN: U4.74, U24.19
SLV_RD: U4.56, U5.16
SLV_WR: U4.57, U5.17
SPLIT: U4.61, U5.20
SRAM_WIN: U4.70, U22.15
XFR16: U4.60, U5.18
XTALI: U1.50, Y1.1
XTALO: U1.49, Y1.2
Z_AS: U1.27, U4.12, U5.54
Z_BUSACK: U1.31, U4.25, U15.1, U16.1, U17.1, U18.1, U19.1
Z_BUSREQ: U1.28, U4.29
Z_BW: U1.10, U4.17
Z_CLK: U1.47, U4.83, U5.83
Z_DS: U1.24, U4.15, U5.55
Z_IE: U1.17, U4.24
Z_INT: U1.37, U5.56
Z_NMI: U1.39, U5.57
Z_RESET: U1.38, U4.27, U13.2
Z_RW: U1.12, U4.16
Z_RXD: U1.48, U14.12
Z_ST0: U1.14, U4.18
Z_ST1: U1.15, U4.20
Z_ST2: U1.21, U4.21
Z_ST3: U1.22, U4.22
Z_TXD: U1.46, U14.11
Z_WAIT: U1.29, U4.28

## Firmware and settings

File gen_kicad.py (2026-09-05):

#!/usr/bin/env python3
"""Generate a KiCad 9 hierarchical schematic for the Z280 -> S-100 CPU card.

Signal-level connectivity follows extra/docs/z280-s100-cpu-card.md. Pin numbers
are verified against the datasheets for the standard parts, the Z280, the
ATF1508 and the S-100 connector (see the NOTES.md this script writes).
"""
import os, uuid

OUT = os.path.dirname(os.path.abspath(__file__))
V = "20250114"  # KiCad 9

_UUID_NS = uuid.uuid5(uuid.NAMESPACE_URL, "z280-s100")

def uid(key):
    """Return a deterministic UUID (v5, dashed) derived from a stable string key.

    Every object in the schematic gets a UUID hashed from its identity (symbol
    reference, pin number, net + position) rather than a fresh random one. This
    keeps the symbol-instance UUIDs stable across regenerations so the board's
    ``(path "/<symbol-uuid>")`` links survive "Update PCB from Schematic" instead
    of churning every time the sheet is re-emitted.
    """
    return str(uuid.uuid5(_UUID_NS, key))

# Root-sheet UUID: shared between the header (uuid ...) and every symbol's
# instances-block path, so KiCad can resolve each per-instance reference.
SHEET_UUID = None

E = {"P": "passive", "I": "input", "O": "output", "B": "bidirectional",
     "W": "power_in", "T": "tri_state", "OC": "open_collector"}

# name -> (ref_prefix, value, footprint, [ (num, name, elec), ... ])
PARTS = {}

PARTS["Z280"] = ("U", "Z280 Z-BUS (12 MHz)", "Package_LCC:PLCC-68_THT-Socket",
    [("1","GND","W"), ("2","AD13","B"), ("3","AD14","B"), ("4","AD15","B"),
     ("5","A16","O"), ("6","A17","O"), ("7","A23","O"), ("8","A18","O"),
     ("9","A19","O"), ("10","B/W","O"), ("11","DMASTB0","O"), ("12","R/W","O"),
     ("13","DMASTB1","O"), ("14","ST0","O"), ("15","ST1","O"), ("16","OE","O"),
     ("17","IE","O"), ("18","VCC","W"), ("19","VCC","W"), ("20","CTIO1","B"),
     ("21","ST2","O"), ("22","ST3","O"), ("23","CTIO2","B"), ("24","DS","O"),
     ("25","CTIN2","I"), ("26","INT-C","I"), ("27","AS","O"), ("28","BUSREQ","I"),
     ("29","WAIT","I"), ("30","CTIO0/GREQ","B"), ("31","BUSACK","O"), ("32","CTIN0/GACK","I"),
     ("33","PAUSE","I"), ("34","OPT","I"), ("35","GND","W"), ("36","INT-B/EOP-B","I"),
     ("37","INT-A/EOP-A","I"), ("38","RESET","I"), ("39","NMI","I"), ("40","AD0","B"),
     ("41","CTIN1","I"), ("42","AD1","B"), ("43","AD2","B"), ("44","AD3","B"),
     ("45","A20","O"), ("46","TXD","O"), ("47","CLK","O"), ("48","RXD","I"),
     ("49","XTALO","O"), ("50","XTALI","I"), ("51","GND","W"), ("52","RESERVED","P"),
     ("53","GND","W"), ("54","AD4","B"), ("55","RDY0","I"), ("56","RDY1","I"),
     ("57","AD5","B"), ("58","RDY3","I"), ("59","A21","O"), ("60","AD6","B"),
     ("61","AD7","B"), ("62","AD8","B"), ("63","RDY2","I"), ("64","AD9","B"),
     ("65","AD10","B"), ("66","A22","O"), ("67","AD11","B"), ("68","AD12","B")])

CPLD_A_IO = [
    ("Z_AS","I"),
    ("Z_DS","I"),
    ("Z_RW","I"),
    ("Z_BW","I"),
    ("Z_ST0","I"),
    ("Z_ST1","I"),
    ("Z_ST2","I"),
    ("Z_ST3","I"),
    ("Z_IE","I"),
    ("Z_BUSACK","I"),
    ("Z_CLK_IN","I"),
    ("Z_RESET","I"),
    ("SLAVE_ONLY","I"),
    ("S100_HOLD","I"),
    ("S100_pRDY","I"),
    ("S100_XRDY","I"),
    ("S100_ADSB","I"),
    ("S100_SDSB","I"),
    ("S100_CDSB","I"),
    ("SRAM_WIN","I"),
    ("FLASH_WIN","I"),
    ("SLAVE_WIN","I"),
    ("A20","I"),
    ("LA0","I"),
    ("Z_WAIT","O"),
    ("Z_BUSREQ","O"),
    ("CPLD_sMEMR","B"),
    ("CPLD_sWO","B"),
    ("CPLD_sINP","B"),
    ("CPLD_sOUT","B"),
    ("CPLD_sINTA","B"),
    ("CPLD_sHLTA","B"),
    ("CPLD_sXTRQ","B"),
    ("CPLD_pSYNC","O"),
    ("CPLD_pSTVAL","O"),
    ("CPLD_pDBIN","O"),
    ("CPLD_pWR","O"),
    ("CPLD_pHLDA","O"),
    ("MEM_CE0","O"),
    ("MEM_CE1","O"),
    ("MEM_OE","O"),
    ("MEM_WE_L","O"),
    ("MEM_WE_H","O"),
    ("FLASH_CE","O"),
    ("FLASH_OE","O"),
    ("FLASH_WE","O"),
    ("CFG_OE","O"),
    ("S100_A_OE","O"),
    ("S100_S_OE","O"),
    ("S100_C_OE","O"),
    ("MST_RD","O"),
    ("MST_WR","O"),
    ("SLV_RD","O"),
    ("SLV_WR","O"),
    ("XFR16","O"),
    ("SPLIT","O"),
    ("SLAVE","O"),
    ("S100_SIXTN","B"),
    ("TCK","I"),
    ("TMS","I"),
    ("TDI","I"),
    ("TDO","O"),
]
# Verified ATF1508 84-pin PLCC power pins (VCCINT/VCCIO/GND), shared by both CPLDs.
# Also the three dedicated inputs we tie INACTIVE (+5V): GCLR (global clear,
# active low) on pin 1, OE2 on pin 2, OE1 on pin 84. They must not float. GCLK1
# (pin 83) is the clock and is handled as Z_CLK_IN in the signal maps.
_ATF1508_POWER = [
    ("3","VCCINT","W"), ("43","VCCINT","W"),
    ("13","VCCIO","W"), ("26","VCCIO","W"), ("38","VCCIO","W"),
    ("53","VCCIO","W"), ("66","VCCIO","W"), ("78","VCCIO","W"),
    ("7","GND","W"), ("19","GND","W"), ("32","GND","W"), ("42","GND","W"),
    ("47","GND","W"), ("59","GND","W"), ("72","GND","W"), ("82","GND","W"),
    ("1","GCLR","I"), ("2","OE2","I"), ("84","OE1","I"),
]

# signal -> physical pin, matching z280-s100-ctl.pld (the decider; verified
# against the ATF1508 PLCC-84 pinout; JTAG TDI/TMS/TCK/TDO at 14/23/62/71).
_A_PIN = {
    "MEM_WE_H": 4,
    "MEM_OE": 5,
    "MEM_WE_L": 6,
    "MEM_CE1": 8,
    "A20": 9,
    "MEM_CE0": 10,
    "CFG_OE": 11,
    "Z_AS": 12,
    "TDI": 14,
    "Z_DS": 15,
    "Z_RW": 16,
    "Z_BW": 17,
    "Z_ST0": 18,
    "Z_ST1": 20,
    "Z_ST2": 21,
    "Z_ST3": 22,
    "TMS": 23,
    "Z_IE": 24,
    "Z_BUSACK": 25,
    "Z_RESET": 27,
    "Z_WAIT": 28,
    "Z_BUSREQ": 29,
    "CPLD_sINTA": 30,
    "CPLD_sHLTA": 31,
    "S100_HOLD": 33,
    "S100_pRDY": 34,
    "S100_XRDY": 35,
    "S100_ADSB": 36,
    "S100_SDSB": 37,
    "S100_CDSB": 39,
    "S100_SIXTN": 40,
    "CPLD_pSYNC": 41,
    "CPLD_pSTVAL": 44,
    "CPLD_pDBIN": 45,
    "CPLD_pWR": 46,
    "CPLD_pHLDA": 48,
    "CPLD_sMEMR": 49,
    "CPLD_sWO": 50,
    "CPLD_sINP": 51,
    "CPLD_sOUT": 52,
    "MST_RD": 54,
    "MST_WR": 55,
    "SLV_RD": 56,
    "SLV_WR": 57,
    "SLAVE": 58,
    "XFR16": 60,
    "SPLIT": 61,
    "TCK": 62,
    "LA0": 63,
    "SLAVE_ONLY": 64,
    "CPLD_sXTRQ": 65,
    "S100_A_OE": 67,
    "S100_S_OE": 68,
    "S100_C_OE": 69,
    "SRAM_WIN": 70,
    "TDO": 71,
    "FLASH_WIN": 73,
    "SLAVE_WIN": 74,
    "FLASH_OE": 79,
    "FLASH_WE": 80,
    "FLASH_CE": 81,
    "Z_CLK_IN": 83,
}
_cpld_a_pins = [(str(_A_PIN[name]), name, elec) for name, elec in CPLD_A_IO]
_cpld_a_pins += _ATF1508_POWER
PARTS["ATF1508"] = ("U", "ATF1508AS (PLCC-84)", "Package_LCC:PLCC-84_THT-Socket", _cpld_a_pins)
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

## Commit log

2026-08-21 Z280 S-100 CPU card: generators + KiCad files
    Initial import (relocated from the micronix tree). The PCB imports the
    real S-100 card outline from s100_Z80 V2.brd, uses the library PLCC
    THT-Socket footprints, and fits every footprint inside the edge.
    [z280-s100.kicad_pcb, z280-s100.kicad_sch]
2026-08-27 Z280 S-100: 4-layer PCB with power planes and edge-connector test points
    gen_pcb.py now emits a 4-layer board (In1.Cu = GND plane, In2.Cu = +5V
    plane), imports the S-100 edge connector geometry from the Z80 V3
    reference board, and adds a row of test-point vias above each connector
    finger. Component reference designators are synced to the schematic's
    current annotation (the edge connector is J8). The schematic generator
    gained the serial header and symbol text/body layout fixes, and the
    schematic, netlist, and PCB were regenerated.
    [z280-s100.kicad_pcb, z280-s100.kicad_sch]
2026-08-28 Z280 S-100: re-partition CPLDs, external decode, reset/BTI config
    Split the two ATF1508s by function: z280-s100-ad.pld (data path) owns
    AD0-15 demux/burst/byte-mux, z280-s100-ctl.pld (decider) owns the FSM,
    arbitration, memory control and steering. Replace the old
    control.pld/data.pld pair.
    Move A16-23 decode off-chip to a 74F138 + two 74F521s (SRAM/FLASH/slave
    window); drop the 74HC573 latches. Boot ROM is now 2x AT28C256 (word-wide
    fetch needs two parts).
    Add reset/BTI loading: a 74HCT244 tri-state driver (CFG_OE-gated) drives
    AD0-7 during reset, config jumpers J10-J17 strap the BTI value, and a
    15-clock hold counter keeps WAIT asserted past reset. Fix dedicated pins
    (GCLR/OE1/OE2 tied i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
    [z280-s100.kicad_pcb, z280-s100.kicad_sch]
2026-08-28 Add sync_pcb.py: read hand-tweaked layout back into gen_pcb.py
    Extracts every footprint's placement (x, y, rotation) from the board file
    and rewrites the matching COMPONENTS/CAPS coordinates in gen_pcb.py, so a
    manually re-jiggered layout is reproduced by the generator on the next run.
    Only entries whose coordinates actually moved are rewritten, keeping the
    diff clean; a no-op round-trip leaves the file untouched. Handles both the
    generator's (at x y rot) form and KiCad's re-serialized (at x y) form where
    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
2026-08-28 Config straps: consolidate 8x 3-pin jumpers into one 3x8 header
    Replace J10-J17 (eight PinHeader_1x03) with a single 24-pin 3x8 header
    (J10): one row per BTI bit, col 0 = +5V, col 1 = BTI_ADn, col 2 = GND.
    Adds a JP3x8 schematic symbol and a hdr_3x8_fp PCB footprint (pin 1
    top-left, row-major, matching the symbol), regenerates the netlist and
    board. DRC clean (0 shorting items).
    [z280-s100.kicad_pcb, z280-s100.kicad_sch]
2026-08-29 Z280 S-100: buffer data bus (74F245), move A3-A15 latch out to 74HC573
    The ATF1508 macrocell outputs can't meet the IEEE-696 24 mA data-bus sink
    spec, so DO0-7 / DI0-7 now run through two 74F245 transceivers (64 mA sink).
    DO_DIR / DI_DIR from the data CPLD drive their DIR pins; /OE is tied low
    (a 245 in receive mode never drives the bus, so only DIR has to be right),
    and both DIRs are DODSB-gated so a temporary master can float the drivers.
    To free the two CPLD pins for those DIRs, the plain A3-A15 half of the
    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
    [z280-s100.kicad_pcb, z280-s100.kicad_sch]
2026-08-29 Z280 S-100: fix schematic annotations; rework schematic + PCB placement
    The schematic was showing every reference as anonymous (U?, Y?) in KiCad.
    Root cause: the symbol instances-block `path` was a filesystem path instead
    of the root-sheet UUID, so KiCad couldn't resolve per-instance references.
    Also `fields_autoplaced` was "no" (KiCad 9 wants "yes") and the
    `sheet_instances` block was missing. Fixed all three.
    Schematic placement: console (MAX232 + serial header) moved to the S-100
    connector column; U25/U26 data-bus buffers given vertical spacing; U3 moved
    down; J10 config and U21 BTI driver moved to the CPU column (x=88).
    PCB placement: MAX232 + serial moved under the S-100 connector; da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
    [z280-s100.kicad_pcb, z280-s100.kicad_sch]
2026-09-01 Z280 S-100: deterministic schematic UUIDs; unify S-100 footprint name
    uid() now derives each schematic UUID from a stable identity key (uuid5) instead of uuid4, so regenerating the schematic no longer churns symbol UUIDs; the board's footprint (path ...) links survive Update PCB from Schematic.
    S-100 edge connector footprint unified on S100_MALE (the schematic carried a phantom Connector_Edge that broke net updates). Sync U27/Y2/U13/J7 positions from the schematic; regenerate the netlist and update the board's 42 footprint path UUIDs to match.
    Also rename decode signal BANK -> A20 and convert DIP/header placements to library footprints in gen_pcb.py.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
    [z280-s100.kicad_pcb, z280-s100.kicad_sch]
2026-09-04 Z280 S-100: clean 2+2 stackup — GND/+5V planes, +8V island, ready to route
    - GND plane on In1.Cu, +5V plane on In2.Cu (through-hole thermal relief)
    - +8V copper island on In2.Cu (bottom-left) feeding the two regulators
    - 18 decoupling caps placed on-board; memory chips U6-U11 spread to 24 mm pitch
    - test-point finger->via traces restored from hand layout; signal routing cleared to a clean slate
    - gen_pcb.py positions synced to the hand-tweaked placement
    [z280-s100.kicad_pcb]
2026-09-05 Z280 S-100: CPLD pin re-site, SLAVE_ONLY strap, full route + patch area
    - Re-pin both CPLDs so signals sit on the package side facing their
    consumers (memory enables up, Z-BUS left, steering right, S-100
    status/control down).
    - Restore SLAVE_ONLY debug strap (arbitration: SLAVE = !Z_BUSACK #
    SLAVE_ONLY) + J11 2-pin header + R3 1k pull-down.
    - Move interrupts (S100_INT/NMI, Z_INT/Z_NMI) to the data CPLD to free
    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
    [z280-s100.kicad_pcb, z280-s100.kicad_sch]
2026-09-05 Z280 S-100: relabel 74F bus parts, silk values, CPLD JEDECs + pin docs
    - Address/status/control drivers 74HCT245 -> 74F245; address latch 74HC573 ->
    74F573. 74ACT245/74ACT573 are documented drop-in substitutes at build time
    if the F parts draw too much +5V.
    - Move footprint Value from F.Fab to F.SilkS and strip the descriptive
    suffixes so the silkscreen matches the hand-edited board (74F245, 74F573,
    74F138, ...). F.Fab stays a comment-only layer.
    - Generate ATF1508 JEDECs for the re-sited CPLDs (ad: 53 MC/3 FF, ctl: 43 MC/7
    FF; pin assignments kept). Document unused I/O for a board rev 2: U5 has
    65/67/68/69/70/73/74 free, U4 has 75/76/77 free + Z_AS (pin 12) as a spare.
    Co-Autho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
    [z280-s100.kicad_pcb, z280-s100.kicad_sch]
2026-09-05 Z280 S-100: fabrication output for rev 1 boards (Gerbers + drill)
    [z280-s100-B_Cu.gbr, z280-s100-B_Mask.gbr, z280-s100-B_Silkscreen.gbr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]
2026-09-05 Document as-built state; add BUGS.md for the S-100 reset gap
    - NOTES.md: drop the "verify before PCB" framing, stale .pld filenames and
    wiring-gap leftovers; note SLAVE_WIN is hardwired (not DIP-strappable).
    - README.md: fix the memory map — SLAVE_WIN is hardwired to 000000-1FFFFF.
    - BUGS.md: S-100 RESET isn't OR'd into Z_RESET (rev 2 fix), plus the
    configurable-slave-window idea for high-order address-line jumpers.
    [gen_kicad.py]
